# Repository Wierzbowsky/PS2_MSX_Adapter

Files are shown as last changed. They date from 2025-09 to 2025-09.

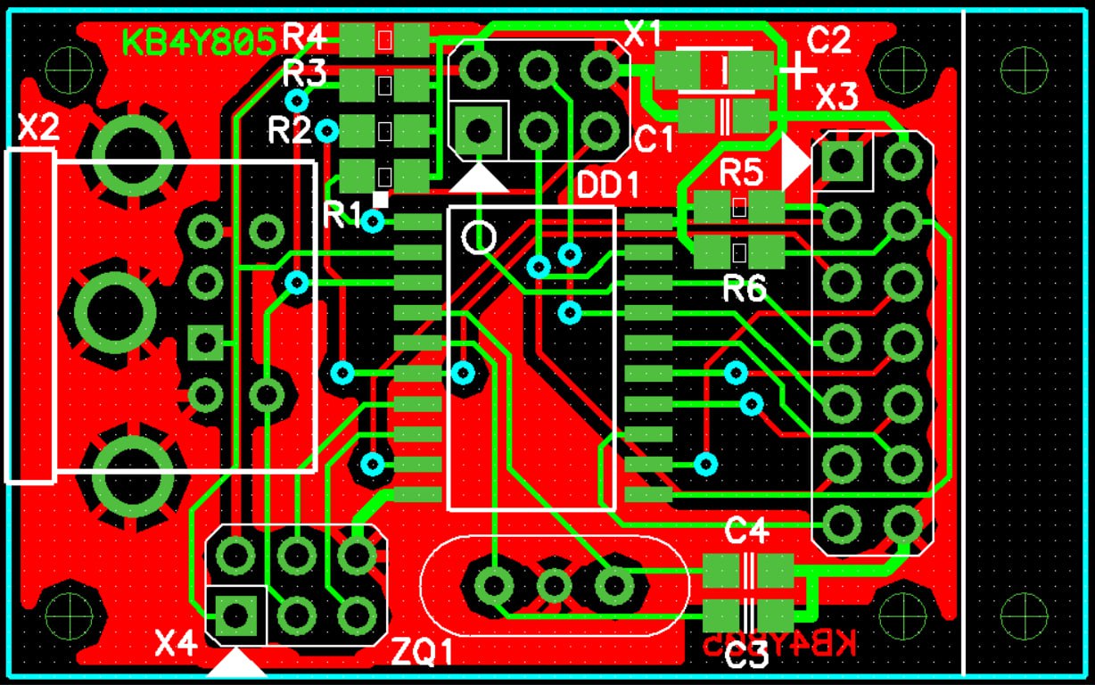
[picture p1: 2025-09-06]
Board/board.jpg

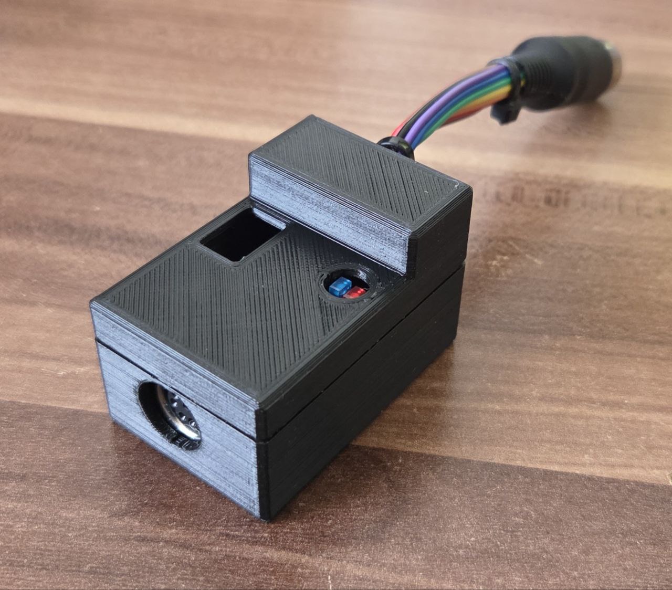
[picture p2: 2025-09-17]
Case/case.jpg

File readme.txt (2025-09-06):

PS/S Keyboard Adapter for MSX2 Computers
----------------------------------------

Designed by Kamil Karimov (k2k@list.ru)
Homepage: http://caro.su/

This reposity contains Gerber files as well as firmware and schematics for the PS/2 keyboard adapter for
MSX2 computers. Four different computer type are supported: Sony F500, F700, F900; Daewoo 400 and 400S;
Yamaha YIS-805 and Sakhr AX-500. All these computers have external keyboards that may be lost of damaged
beyond repaid. The PS/2 keyboard adapter is the cheapest and the most reasonable replacement for those
damaged or lost keyboards.

Mr. Karimov gave his permission to put his files into the repository. However it's not allowed to use any
of the files in this repository for commercial purposes without the permission from the author. Making a
small batch of boards, using some of the boards for personal projects and selling the remaining boards is
permitted.

The project can use either Attiny 2313 or 4313 chip. See the partslist.txt file for the information on
the necessary components. The design of the circuit board is the same for 4 variants of this adapter,
only the firmware differs.

The board needs to be programmed after assembling. We recommend to use an USBASP or clone programmer and
the special 2x3 pin adapter for programming the board. Please observe the polarity when connecting the
USBASP programmer. The AVRDUDE software that is included into the repository is configured to use the
generic USBASP programmer. If you use a different programmer, you may need to adjust the batch files
accordingly. The programmer must be connected to the X1 connector.

The FUSES.txt file contains information on how to set correct fuses for 2313 or 4313 chip. Normally,
the AVRDUDE software takes care of this itself, but in case your programmer needs to set fuses itself,
please see the file for reference.

The DIN-13 connector that is used to connect the PS/2 adapter to an MSX2 computer has different pinouts
for different computers. Please see the connection diagram for each computer in the Schematics folder.
As most of the currently sold DIN-13 connectors are machined and not suitable for soldering, it's
recommended to use female-to-female jumber wires to connect the 14-pin header to the DIN connector. For
that, the plastic cover should be removed from one side of the wire and a shrinktube of matching size
should be put onto the terminal. Then the terminal's end should be slightly widened to fit onto the
machined end of the DIN-13 connector. That's the only reasonable way to wire up the connector. There's
an alternative - to buy the already wired connector and cut its cable in half.

DIN-13:
Din Plug 13 Pin Male Inline Audio Adapter Connector
https://de.aliexpress.com/item/1005006533940348.html

Jumper wires:
10/40PIN Cable Dupont Female to Female Jumper Wire
https://de.aliexpress.com/item/1005004647016228.html

DIN-13 cable (option):
1M/3M 13 Pin to 13 Pin DIN CD Changer to Head Unit Extension Cable for Kenwood Tuner
https://de.aliexpress.com/item/1005004895215380.html

For the Yamaha YIS-805 MSX2 computer there exist 2 different firmwares - kbd2yis805_SU.hex where a user
needs to press the Shift key to type numbers and the kbd2yis805_RU.hex where numbers are typed without
the Shift key.

The Gerber files for the board with LEDs is not provided as this is an optional part. But there's a
scematics in the Schematics folder that shows how LEDs should be connected to the board (X4 connector).

PS/2 keyboard layout for Yamaha YIS-805 and Sakhr AX-500:

; SELECT   - F11
; STOP     - F12
; CLS/HOME - Home
; INS      - Ins
; DEL      - Del
; GRAPH    - Alt left or right
; PYC      - Scroll Lock

PS/2 keyboard layout for Sakhr AX-500:

; SELECT   - F11
; STOP     - F12
; CLS/HOME - Home
; INS      - Ins
; DEL      - Del
; GRAPH    - Alt left or right
; CODE     - Scroll Lock

PS/2 keyboard layout for Sony F500, F700 and F900 series:

; SELECT   - F11
; STOP     - F12
; CLS/HOME - Home
; INS      - Ins
; DEL      - Del
; GRAPH    -  Alt left or right
; CODE     -  FlyWin left or right
; DEAD     -  Scroll Lock

PS/2 keyboard keys for Daewoo 400 or 400s:

; SELECT   - F11
; STOP     - F12
; CLS/HOME - Home
; INS      - Ins
; DEL      - Del
; GRAPH    - Alt left or right
; CODE     - Scroll Lock

Please note that Korean, Japanese or Arabic character maps may be inaccurate because there was no way to
verify the input without knowing any of those languages. The main purpose of this adapter is to provide
basic keyboard functionality (Latin characters, numbers and special symbols with Graph). Anomalies and
bugs should be reported to RBSC (info@rbsc.su).

The video that shows how the keyboard adapter works could be found here:
https://www.youtube.com/watch?v=sjwlw_10PEQ

IMPORTANT!
The commercial usage of this project is not allowed without the permission of the author! There's no
guarantee of any kind for the provided material and the author must not be held responsible for any
possible use or misuse of the adapter as well as for any possible damages.

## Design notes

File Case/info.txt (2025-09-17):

PS/S Keyboard Adapter for MSX2 Computers
----------------------------------------

This basic case was created by Wierzbowsky. The case was created specifically for
the cable that has DIN-13 on one end and Dupont 2x7 connectors on the other end.
Dupont connectors sit too high on the 2x7 pin header, so the case has a higher
compartment to host the cable and prevent it from bending too much.

Use black laptop screws 2x8mm to join the upper and lower parts of the case. Do
not overtighten these screws, otherwise the connection will be bad. It's also
possible to use other screws, for example 2.5x8mm for wood/plastic for the case.

The case has a hole for reprogramming the adapter and also another hole for an
optional LED board that can be made from a piece of a breadboard.

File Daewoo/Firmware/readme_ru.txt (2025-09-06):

Версия прошивки контроллера ATTiny2313/4313 для работы
одиночной платы kb4y805 в версии c PS/2 клавиатурой в
режиме эмуляции внешней клавиатуры компьютера DAEWOO CPC400.
PS/2 клавиатура работает в режиме Scancode 2.
; Служебные клавиши:
; SELECT -  F11
; STOP   -  F12
; CLS/HOME - Home
; INS - Ins
; DEL - Del
; GRAPH  -  Alt левый и правый
; CODE   -  Scroll Lock

kbd2_D400.hex

01/05/2023
Kamil Karimov (caro)

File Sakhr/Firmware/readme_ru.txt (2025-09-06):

Версия прошивки контроллера ATTiny2313/4313 для работы
одиночной платы kb4y805 в версии c PS/2 клавиатурой в
режиме эмуляции внешней клавиатуры компьютера AX-500.
PS/2 клавиатура работает в режиме Scancode 2.
; Служебные клавиши:
; SELECT -  F11
; STOP   -  F12
; CLS/HOME - Home
; INS - Ins
; DEL - Del
; GRAPH  -  Alt левый и правый
; CODE    -  Scroll Lock

kbd2AX500.hex

01/05/2023
Kamil Karimov (caro)

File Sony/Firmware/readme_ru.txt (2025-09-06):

Версия прошивки контроллера ATTiny2313/4313 для работы
одиночной платы kb4y805 в версии c PS/2 клавиатурой в
режиме эмуляции внешней клавиатуры компьютера SONY MSX.
PS/2 клавиатура работает в режиме Scancode 2.
; Служебные клавиши:
; SELECT -  F11
; STOP   -  F12
; CLS/HOME - Home
; INS - Ins
; DEL - Del
; GRAPH  -  Alt левый и правый
; CODE   -  FlyWin левый и правый
; DEAD   -  Scroll Lock

kbd2_sony.hex
  
01/05/2023
Kamil Karimov (caro)

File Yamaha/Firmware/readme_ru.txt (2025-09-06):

Версия прошивки контроллера ATTiny2313/4313 для работы
одиночной платы kb4y805 в версии c PS/2 клавиатурой в
режиме эмуляции внешней клавиатуры компьютера YIS805.
PS/2 клавиатура работает в режиме Scancode 2.
; Служебные клавиши:
; SELECT -  F11
; STOP   -  F12
; CLS/HOME - Home
; INS - Ins
; DEL - Del
; GRAPH  -  Alt левый и правый
; РУС    -  Scroll Lock
Две версии прошивки для разных версий ПЗУ в YIS805
kbd2yis805_SU.hex - для ПЗУ с набором цифр при нажатом SHIFT
kbd2yis805_RU.hex - для ПЗУ с набором цифр без нажатия SHIFT

01/05/2023
Kamil Karimov (caro)

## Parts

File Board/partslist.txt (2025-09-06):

Partslist
---------

Components:

D1 - ATTINY2313A-SU or ATTINY4313 (SOP-20)
R1 - 10k 0805 chip resistor
R2 - 2k 0805 chip resistor
R3 - 2k 0805 chip resistor
R4 - 2k 0805 chip resistor
R5 - 10k 0805 chip resistor
R6 - 1k 0805 chip resistor
C1 - 100nF 0805 ceramic capacitor
C2 - 10-47uF 1206 ceramic capacitor
C3 - 22pF 0805 ceramic capacitor
C4 - 22pF 0805 ceramic capacitor
ZQ1 - Crystal oscillator 20.000 MHz

Connectors:

X2 - 6-pin female PS/2 connector for keyboards
X3 - 2x7 male pin header
X1 - 2x3 pin female connector or 2x3 male pin header (for easy connection to the programmer)
X4 - 2x3 pin female connector

Plugs:

DIN-13 male connector

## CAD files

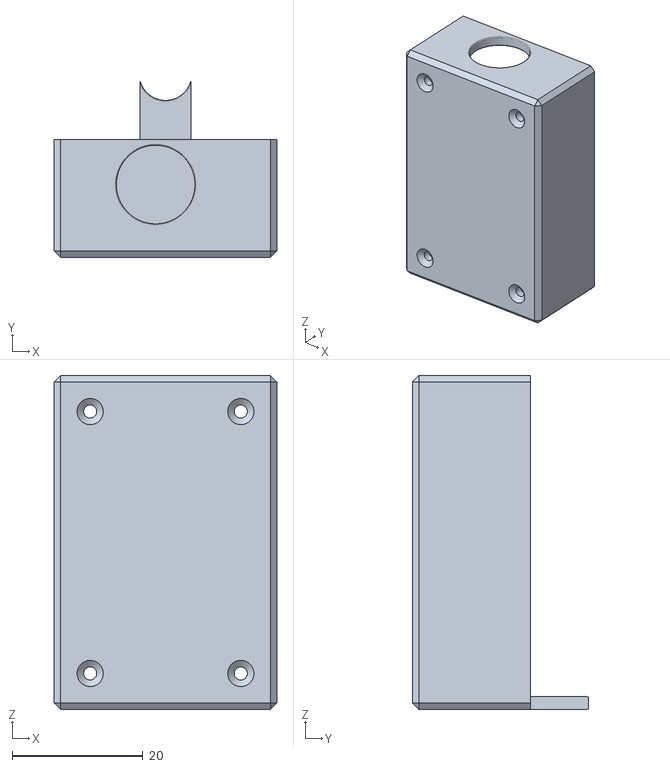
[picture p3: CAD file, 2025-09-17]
Case/KbdAdapterBottom.stl
34.0 x 26.9 x 51.0

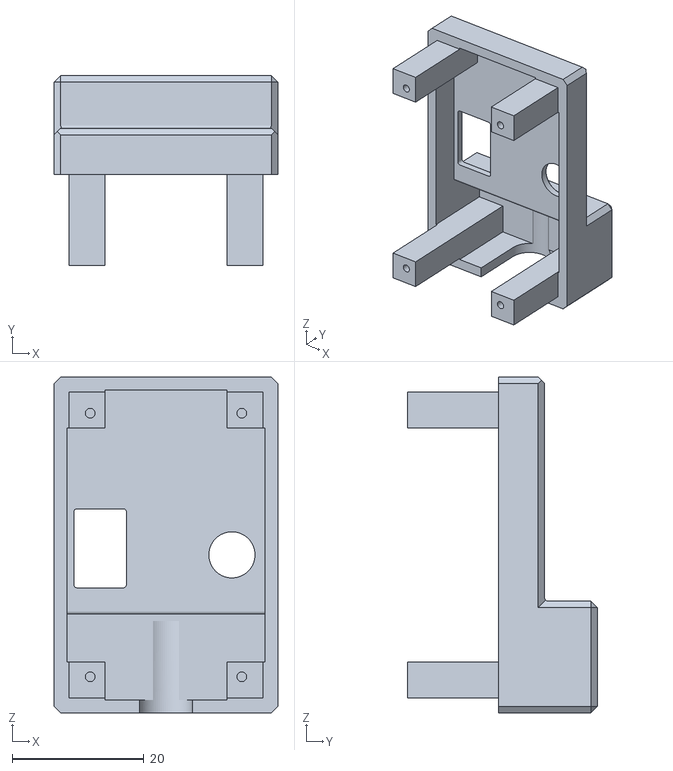
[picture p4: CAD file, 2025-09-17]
Case/KbdAdapterTop.stl
34.0 x 28.8 x 51.0

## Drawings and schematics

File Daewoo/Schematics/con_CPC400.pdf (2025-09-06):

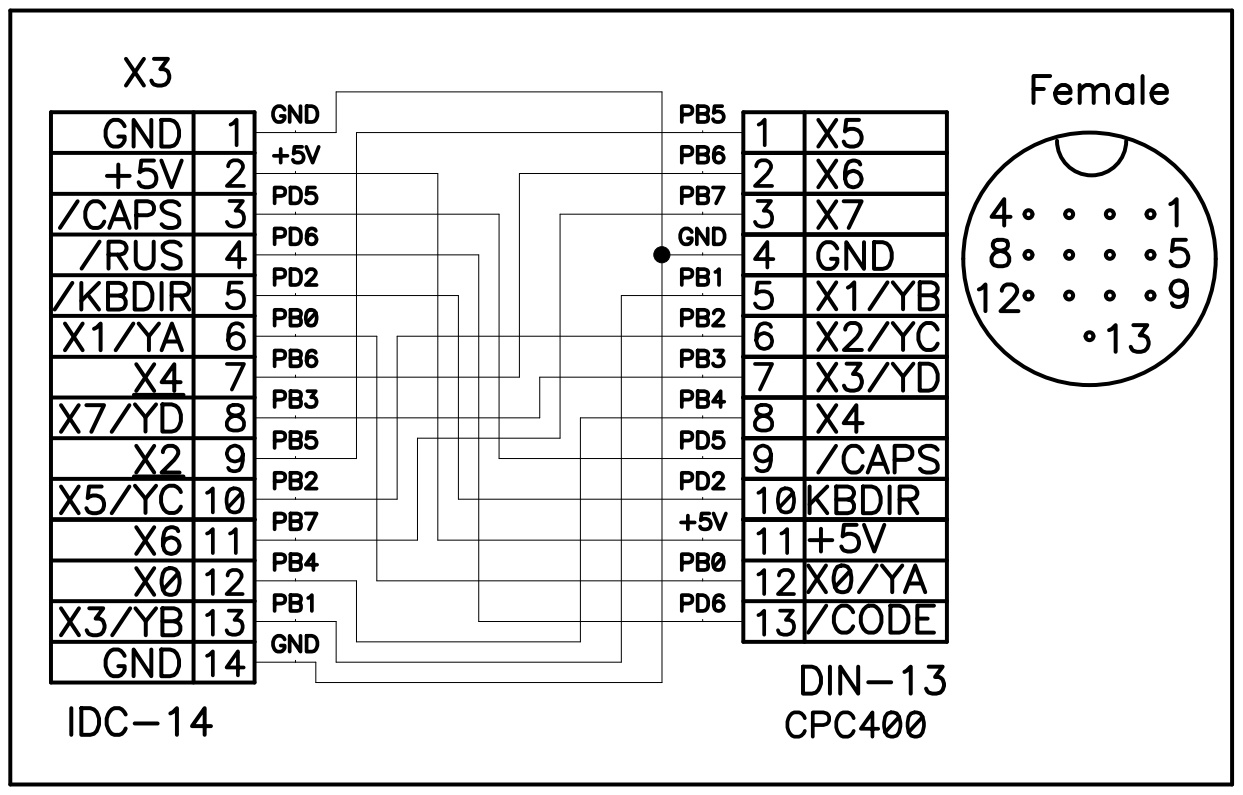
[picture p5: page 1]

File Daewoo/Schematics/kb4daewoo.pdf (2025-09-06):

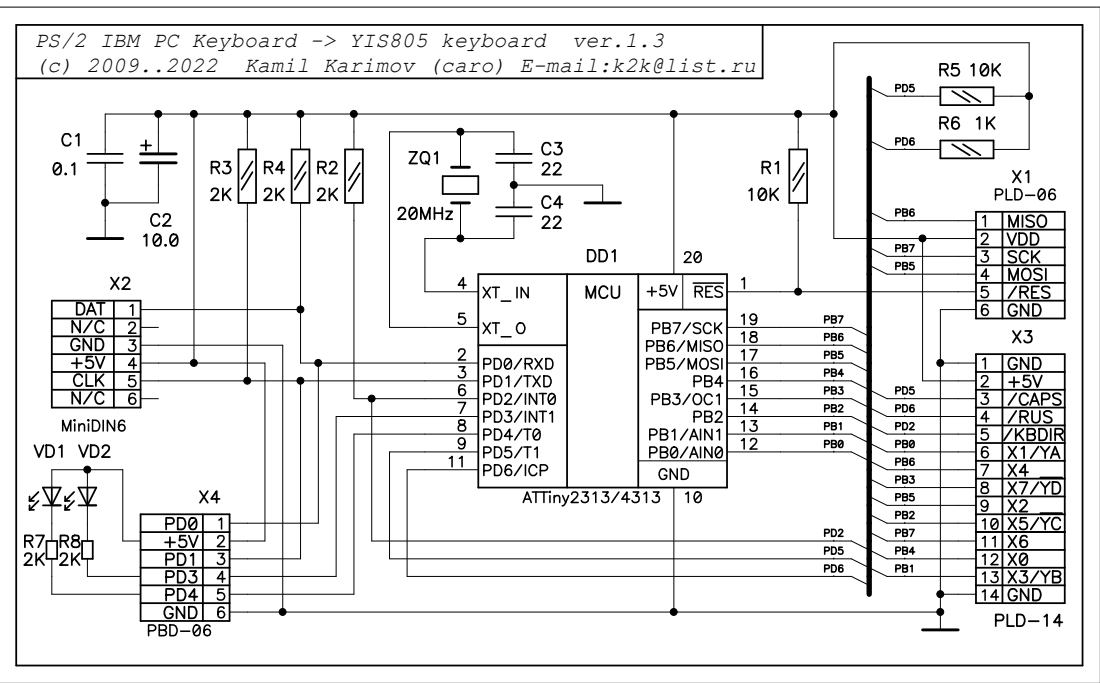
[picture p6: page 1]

PS/2 IBM PC Keyboard -> YIS805 keyboard ver.1.3
(c) 2009..2022 Kamil Karimov (caro) E-mail:k2k@list.ru

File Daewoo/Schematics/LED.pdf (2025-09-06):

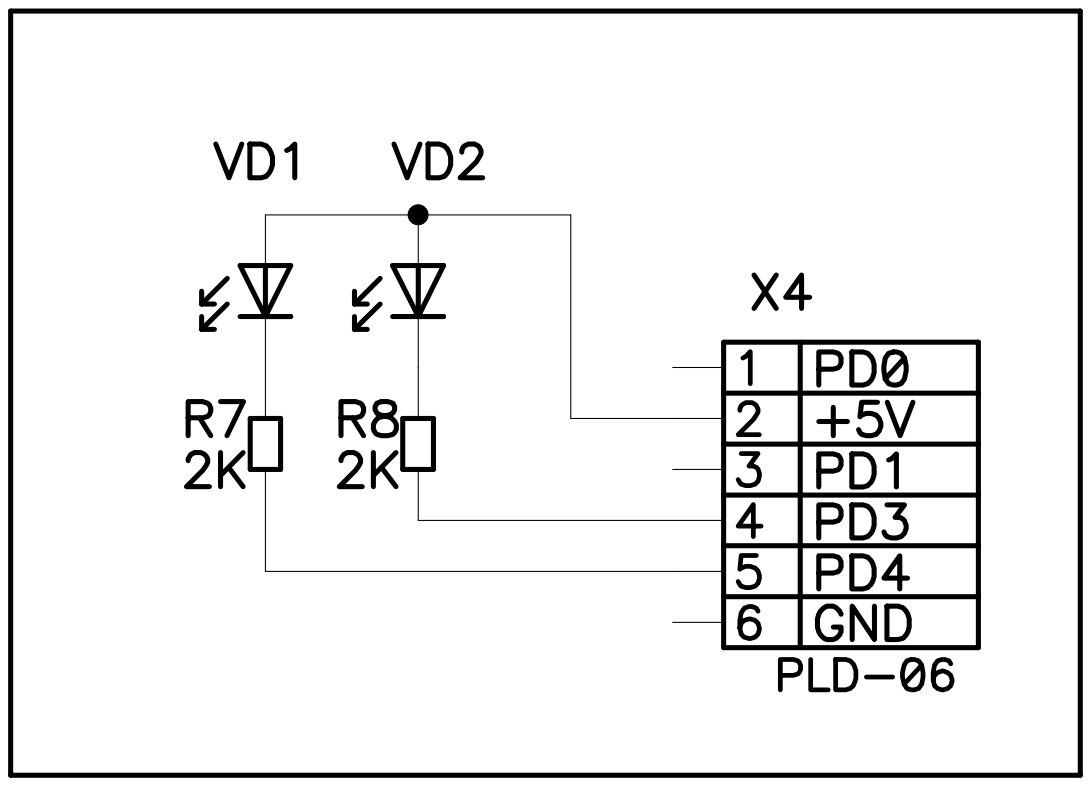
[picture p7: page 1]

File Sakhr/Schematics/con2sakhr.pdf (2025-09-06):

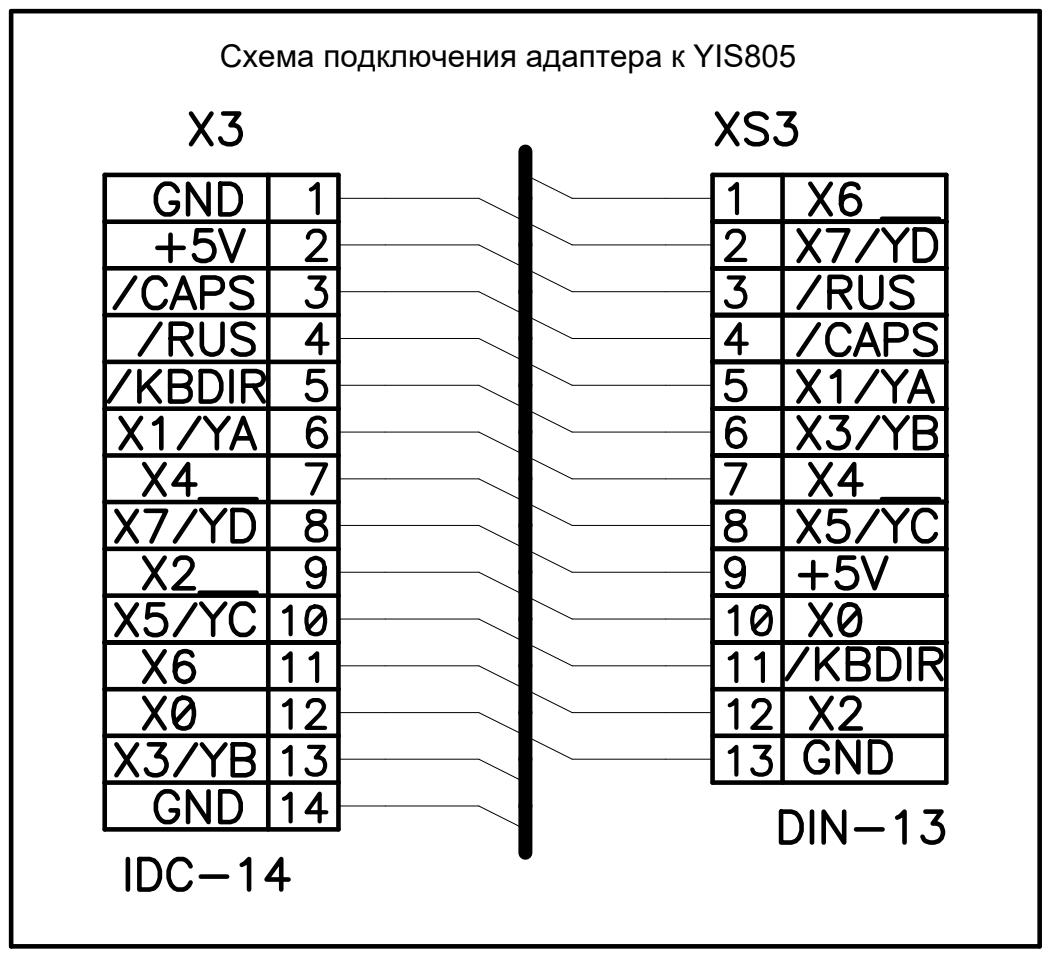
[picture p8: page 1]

Схема подключения адаптера к YIS805

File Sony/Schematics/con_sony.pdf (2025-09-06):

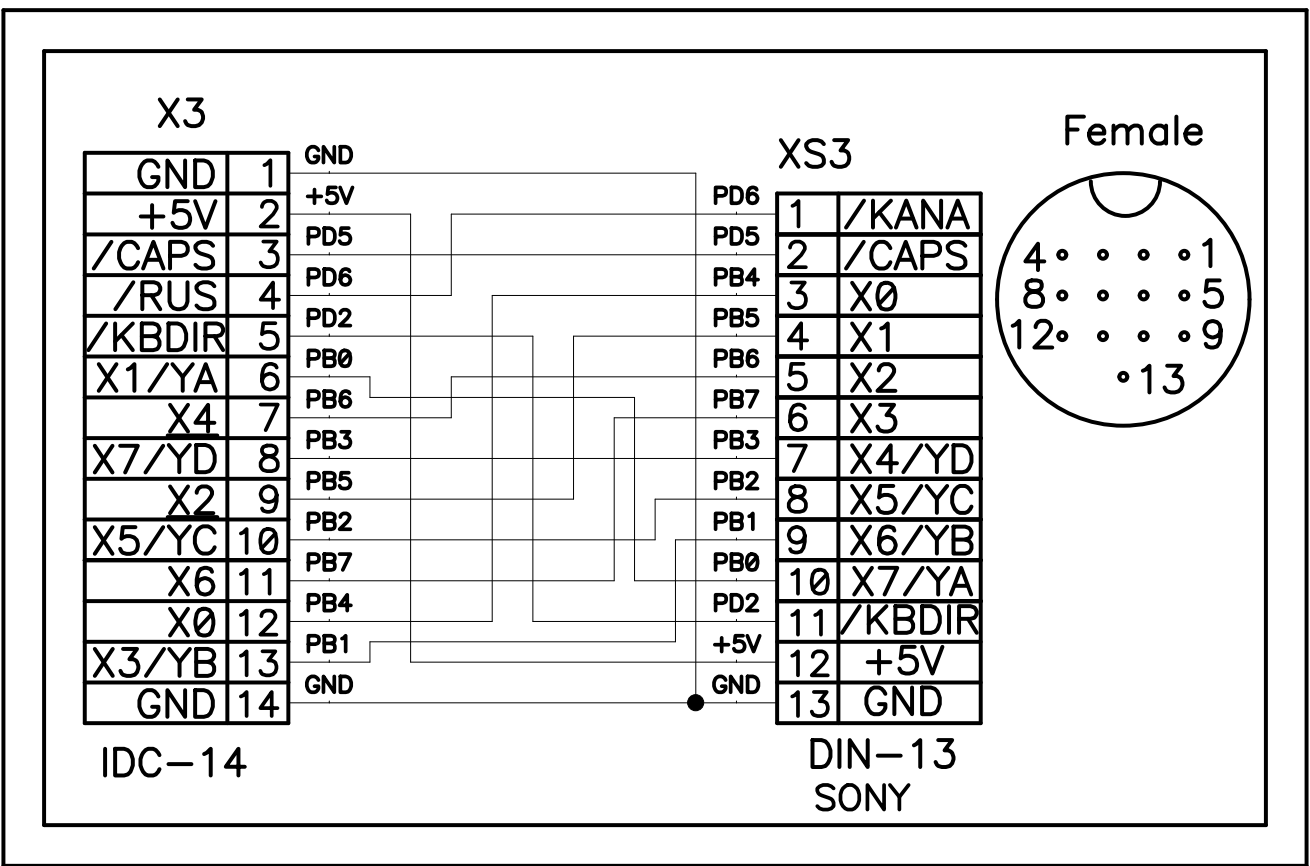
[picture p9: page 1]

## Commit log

2025-09-06 Initial release 06.09.2025
    Initial release of files for PS/2 keyboard adapter
    [KB4Y805__.BRD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]
2025-09-17 Updated 17.09.2025
    Added a basic case for the adapter
    [KbdAdapterBottom.stl, KbdAdapterTop.stl]
